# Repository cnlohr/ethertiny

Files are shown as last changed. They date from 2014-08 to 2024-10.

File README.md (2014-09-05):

WARNING

This is a really dangerous project.  Use at your own risk.

By directly ethernet without magnetics to an AVR, you may
cause serious damage, fire, or anything else crazy if there
is a DC offset.  It does not follow 802.3 standards for
10Base-T Ethernet

It has two projects in it:
 t85: uses differential signaling with fixed packets, similar to another
	person's project, igorplug, found here:
	http://www.cesko.host.sk/IgorPlugUSB/IgorPlug-USB%20%28AVR%29_eng.htm

 t85spi: uses the USI, and can send/receive arbitrary packets.

Schematics are in the "hardware/" folder.

See the youtube video for more info:

T85 Video:    http://youtu.be/mwcvElQS-hM

T85spi Video: http://youtu.be/m4f4OzEyueg

Paper on T85spi is found in the "paper/" folder.

Copyright (C) 2014 <>< Charles Lohr

Permission is hereby granted, free of charge, to any person obtaining a
copy of this software and associated documentation files (the "Software"),
to deal in the Software without restriction, including without limitation
the rights to use, copy, modify, merge, publish, distribute, sublicense,
and/or sell copies of the Software, and to permit persons to whom the
Software is furnished to do so, subject to the following conditions:

The above copyright notice and this permission notice shall be included
in all copies or substantial portions of the Software.

THE SOFTWARE IS PROVIDED "AS IS", WITHOUT WARRANTY OF ANY KIND, EXPRESS
OR IMPLIED, INCLUDING BUT NOT LIMITED TO THE WARRANTIES OF
MERCHANTABILITY, FITNESS FOR A PARTICULAR PURPOSE AND NONINFRINGEMENT.
IN NO EVENT SHALL THE AUTHORS OR COPYRIGHT HOLDERS BE LIABLE FOR ANY
CLAIM, DAMAGES OR OTHER LIABILITY, WHETHER IN AN ACTION OF CONTRACT,
TORT OR OTHERWISE, ARISING FROM, OUT OF OR IN CONNECTION WITH THE
SOFTWARE OR THE USE OR OTHER DEALINGS IN THE SOFTWARE.

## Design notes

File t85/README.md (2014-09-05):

This program just bit bangs data out a differential pair.
Whatever you put as your packet, it will parrot out at 
10 Mbit/sec.

The idea is you modify testpack.txt to be the following from:

:Function Name

[Ethernet bytes in hexadecmil, two letters each]

 ; Anything after a [space] and a semicolon is a comment.

Then, it will create "sendpack.S" with all of the assembly
to go run everything all at once.  In order to send a packet,
simply call the function to send a packet!

If you need to use the other ports for I/O, you'll need
to modify the code to set up the right bits on port B.

Right now, port PB3,PB4 are the TX+/TX- pins.
A switch can be connected between PB0 and PB1
and another switch may be connected btween PB2 and PB1.

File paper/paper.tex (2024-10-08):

%\documentclass{article}
\documentclass[13pt]{ltxdoc}
\usepackage{graphicx}
\usepackage[margin=1.25in]{geometry}
\usepackage[usenames,dvipsnames]{color}
\usepackage{hyperref}
\usepackage{listings}
\usepackage{float}
%\usepackage{draftwatermark}
%\SetWatermarkText{DRAFT}
%\SetWatermarkScale{8}
\restylefloat{figure}

\begin{document}

\title{Half-Duplex 10Base-T on an ATtiny85}
\author{Charles Lohr}
%\publicationyear{2014}
%\publicationissue{}
%\publicationmonth{September}
\maketitle

\begin{abstract}
The ATtiny85 Processor by Atmel is an 8-bit RISC microcontroller with 8kB of 
flash, 512 bytes of RAM, and a nominal operating frequency of 20 MHz.
10Base-T Ethernet is an interface standard supported by most modern networking
hardware and enables devices to talk to eachother on a network.  Ordinarily,
specialty hardware is needed to send and receive.  However, by abusing
the USI and PLL and overclocking the ATtiny85 processor, while violating the 802.3 standard, we can communicate to devices via 10Base-T on a network.
\end{abstract}

\begin{figure}[ht]
    \centering
    
    \caption{System Schematic}
	\label{fig:schematic}
\end{figure}

\section*{Warning}
This project does not follow standards, and violates recommended operating ranges on the AVR.  It is unlikely
to work with most AVRs or Ethernet-enabled devices, and is completely unacceptable for production designs.
Follow only at your own risk.
\pagebreak
\section{Introduction}

Although there have been those who have successfully sent packets from an AVR to
the Ethernet on an AVR\footnote{Igor \v{C}e\v{s}ko ``Implementation UDP into microcontroller Igor Atmel-UDP device: UDP/IP infrared remote control'' \url{http://www.cesko.host.sk/IgorPlugUDP/IgorPlug-UDP\%20\%28AVR\%29_eng.htm} (Retrieved Sept 2, 2014)}, their approaches have been limited
to fixed packets with at most one byte of payload changing.  This is not ideal
for a general Ethernet device.

The ATtiny85 processor has a core that operates at one clock cycle per instruction
for most instructions\footnote{Atmel ``8-bit AVR Instruction Set'' 0856D–AVR–08/02 (Retrieved Sept 2, 2014)}.  It has a USI (Universal Serial Interface)
that we can use as a high frequency shift register.  If clocked with Timer 0, 
we can achieve a sample rate of the system clock frequency.  This makes it possible
to send out Manchester-encoded Ethernet frames from RAM when operating at 20 MHz. 

When receiving packets, we need to sample at $\approx$31.5 MHz.  This can be achieved
by using the AVR's internal PLL.  Once the AVR is running above 30 MHz, the USI's 
buffer register is polled.  When an Ethernet frame begins, the AVR can dump the 
bitstream to RAM, and at a later time can decode the Ethernet frame in place.

Our physical interface to the Ethernet is intentionally poor and cheap, as can be seen in
Figure \ref{fig:schematic}.  While
it would be wise in more practical situations to use magnetics and proper termination
even a line driver would be great.  We opted to see what the bare minimum is.

\section{Background}

\subsection{Ethernet Topology}
Ethernet uses a point-to-point communication scheme over separate differential pairs of copper wires, one pair for TX one pair for RX. 
All communication to other devices on the network
is done through the use of switches and hubs.  Switches expect the TX and RX lines to
be opposite that of the client device.  We use the client-style +/- pairs.  If we wish
to connect directly to another client, i.e. a laptop, we would need a crossover or the
other computer would need to support MDIX.

The pairs, TX and RX are differential to aid in common-mode rejection.  Noise
will affect both pairs similarly, and the effective noise on the signal will be minimized.
Additionally, 802.3-2002 mandates all Ethernet devices isolated
the incoming signal to help with noise rejection and prevent ground loop issues, but
most prominently, safety benefits.  \footnote{802.3-2002 Section 14.3.1.1}

While detectable, it generally is not a big deal if the +/- on an individual pair
is swapped.  Our algorithm doesn't care which one is + or -.

Because we ground our signals instead of using magnetics, we will get neither of these
benefits.

\subsection{Manchester Encoding}
Ethernet data is encoded in Manchester encoding at 10 MBits/sec.  Manchester encoding
is a continuous stream that focuses on the changes in bits.

With Manchester decoding, focus is on the location of a rising or falling edge.  Falling 
edges on clock pulses indicate a 0, rising edges indicate a 1.  Manchester guarantees that there
should be approximately as many 1's on the wire as 0's, thus preventing DC offsets.  Figure \ref{manchester}
shows an example Manchester encoded stream.  

This data is transmitted on-wire MSB first.  At any one point in time, it is impossible to
determine if a bit is a 1 or a 0 unless the start-of-message bit is found, as there is no
clock source for Ethernet.  Therefore, it is impossible to know if the signal is falling or
rising on the clock edge.

\begin{figure}
    \centering
    
    \caption{Manchester Example}
    \label{manchester}
\end{figure}

One way to decode the Manchester if you know what the first bit is, is to look for any long pulses.
Each long pulse indicates a change in bits, and any pairs of short pulses indicate a repeat in bit. 
When the data transitions from a 0 to a 1 or a 1 to a 0, there is a long pulse. For
the section of the packet with many 0's, there are pairs of short pulses.  Making sure that all
short pulses are paired up helps us detect errors early. 

If there are many repeated output 1's or 0's in a row that can mark the end of an Ethernet packet.
While the Ethernet packet is transmitting, there should never be a period when the line is low
or high for longer than .2us.

In order to match up the first bit of the packet, we have to look for the start signature.
Figure \ref{manchesterb} shows what the beginning of the data in an Ethernet packet looks like.
Once we see the pair of 1's, we now know that the packet is starting and can begin 
decoding the packet.

\begin{figure}
    \centering
    
    \caption{Beginning of frame}
    \label{manchesterb}
\end{figure}

\subsection{IEEE 802.3 Ethernet frame}
The Ethernet frame consists of a preamble, i.e. repeating 0x55's for 7 bytes, with the last
byte being a 0xD5, i.e. the highest bit is flipped to break the chain of alternating low
and high.  This makes it possible for receivers to sync up to the packet at any time during the
preamble.  This can be seen in Figure \ref{manchesterb}.  Practically speaking that gives us $\approx$5uS to begin recording an Ethernet 
before we'll miss the start token and be unable to recover the packet.

Figure \ref{etherfarme} shows us that from there, we have the destination MAC, source MAC, and the rest of our IP packet.
When we're done with the IP Packet, we can have padding so that the frame adds up to 64 bytes, and then at the end, we have an Ethernet CRC.
We had to use a table-less CRC because of the excessive RAM/Flash usage of tabled ones.

\begin{figure}
    \centering
    
    \caption{Ethernet Packet Example}
    \label{etherfarme}
\end{figure}

\subsection{Link Detection}
Ethernet Links are detected using different autonegotiation schemes depending on speed.  Conveniently,
10Base-T, Half-Duplex is trivial to indicate.  It does not need any codes and simply needs to emit
a new NLP pulse every 16ms that's 100-200ns wide.  This pulse is only in one direction and is not a full
up-and-down.

\section{Hardware}
Figure \ref{fig:schematic} shows the specific schematic we used when developing the software stack.
It is particularly terrible.  It terminates poorly, doesn't have any isolation, doesn't drive very strong (violating the
voltage template) \footnote{IEEE 802.3-2002 Figure 14-9}
and doesn't cleanly receive data.  This is the most minimal set up we were able to use to send and receive packets.

While it worked with short cables (\textless 10 meters) with all hardware we connected it.  When tested \textgreater 10 meters,
to a switch it did not link.

\begin{itemize}
\item C1, C2 are bypass capacitors that maintain power to the chip during brief points where it needs extra power, i.e. transitioning states on the TX pin.
\item P1 is any ethernet connector, it may be female or male.
\item C3 is the TX capacitor.  It develops a 2.5v bias, so the output swing (if no load were applied) would be $\pm$2.5v.
\item C4 is the RX capacitor.  It develops a biased voltage across, so the AVR does not interface with negative voltages.
\item R1, R2 produce a bias in order to raise or lower the DC offset of the incoming signal so that the AVR receives approximately as many 1's as 0's.  It also helps prevent state transitions from being missed entirely.  2k was selected because it happens to have lined up with what I had and worked surprisingly well.
\item R3, R4 are termination resistors, to terminate the signal from the network cable.
\item U1 is the ATtiny85 Processor.
\item J1 is the programming header, compliant with the 6-pin AVR ISP header.
\item WS2812 is any series of WS2812 LEDs.
\item SW1 is a switch.  Because PB4 has an internal pull-up resistor.  This switch will ground that pin.
\end{itemize}

Hardware warnings include:
\begin{itemize}
\item The AVR is driving the output directly, and will often be unable to push the output hard enough to reach the needed voltages to match the spec, also it has a noisy output.
\item There is no isolation.  There should be magnetics to help to:
\begin{itemize}
\item Reject common-mode noise, cleaning up the signal.
\item Add safety to prevent DC transients.
\end{itemize}
\item There is no differential receiver. We are relying on the AVR's Schmitt trigger. \footnote{AVR ATtiny85 Datasheet (2586K-AVR-01/08), Figure 10-2}
\end{itemize}

\section{Software Implementation}
IEEE 802.3 specifies a few different speeds for Ethernet.  One of which that is still
widely supported is 10Base-T, which runs at 10 mbits/sec on-wire transfer - and Ethernet
devices today are still reverse compatible with it.
\textsuperscript{IEEE 802.3 Section 28.1.4}.  We will
mimic a 10Base-T device.  For this we will focus on these aspects:

\begin{itemize}
\item Clocking
\item Use of the USI (Universal Serial Interface)
\item Normal Link Pulses (NLP)
\item Transmitting Manchester encoded packets
\item Receiving Manchester encoded packets
\item Overall process.
\end{itemize}

All source code is available on github in the "ethertiny" project.  At the time
of initially writing this paper, all code for this paper was in the "t85spi" folder.

\subsection{Clock}
We opted to
use the USI on the ATtiny85, clocked at the system clock.  This enables us to
write one byte at a time that will be shifted out of the USI over the next eight
clock cycles.  This gives us enough time to Manchester encode bytes of Ethernet
traffic in RAM on-the-fly.  This is good because it means we do not need to pre-
process the packet and we do not need to use extra RAM to store it.

In order to obtain 20 MHz, we arbitrarily picked an OSCCAL value of 0xbb on our
hardware.  Although this should change from chip to chip, we've found that in most
cases, surprisingly, this value seems to hold.  Additionally, we have to configure
the clock fuses to CKSEL=1.  Our fuses for this are found in Listing \ref{lst:avrdude_fuses}.
Default EFUSEs and HFUSEs are acceptable.  We also enable PLLE and PCKE for any additional
hardware as seen in Listing \ref{lst:clkcmd}.

\begin{figure}
\begin{lstlisting}[caption=AVRDude Fuse Command Line\label{lst:avrdude_fuses},, frame=single]
avrdude -c usbtiny -p t85 -U lfuse:w:0x41:m
\end{lstlisting}
\end{figure}

\begin{figure}
\begin{lstlisting}[caption=Clock Setup\label{lst:clkcmd},language=C, frame=single]
PLLCSR = _BV(PLLE) | _BV( PCKE );
OSCCAL = OSC20;
\end{lstlisting}
\end{figure}

To move to $\approx$31.5 MHz for receiving, we simply set OSCCAL to 0xff.  Once done, we move it back to 0xbb for all other operations.

\subsection{USI}
The USI on the ATtiny must be clocked at the system clock in order to input and output the data fast enough.
To do this, we configure Timer 0 to clock at the system clock rate in CTC mode, with a "top" time of 0.
Provided we operate on it every eight clock cycles, we can create or read
a continuous stream of 1's and 0's at the clock rate.

Listing \ref{lst:usisetup} shows the code to activate Timer 0 and configure the USI to use it. 
When reading from the USI, it is important to use the USIDR registers whenever reading or writing to it.

We have to keep the USI disabled when not in use.  If we leave it enabled, data coming in will be shifted through.  
That means that whenever the USI is enabled, we must be constantly filling the incoming buffer or reading the buffer.
We do not want the incoming data from the network to be shifted back out.  It is convenient to leave the USICR setup and then
set the flag to enable it once we're ready to load in new data and go.

\begin{figure}
\begin{lstlisting}[caption=USI Setup\label{lst:usisetup},language=C, frame=single]

	//Setup timer 0 to speed along.
	//It will become useless for any other uses.
	TCCR0A = _BV(WGM01); //CTC mode.
	TCCR0B = _BV(CS00);  //Use system clock with no divisor.
	OCR0A = 0;

	USICR = _BV(USIWM0) | _BV(USICS0) | _BV(USITC);

	//setup port B
	PORTB &= ~_BV(0); 
	DDRB &= ~_BV(0);
	PORTB &= ~_BV(1);
	USICR &= ~_BV(USIWM0);  //Disable USICR

#ifdef SMARTDDR
	DDRB &= _BV(1);
#else
	DDRB |= _BV(1);
#endif

	//Optional, changes bias.
	//2k -> GND/2k ->5V seems best with this on
	//PORTB |= _BV(0);
	//Doesn't change much with it off. 2k/2k it is.
	PORTB &= ~_BV(0);

\end{lstlisting}
\end{figure}

\subsection{NLPs}
10Base-T Ethernet uses link pulses, or a single up-going pulse that lasts 10-20us
every 16ms $\pm$ 8ms \textsuperscript{IEEE802.3 Section 14.2.1.1}.  This is used to tell
the connected Ethernet device that this device is here, that it's alive, and that it's a
10Base-T, Half-duplex device.  Instead of using the USI on the AVR to create this
signal, we opt to manually turn the pin on and off at the correct times in
Listing \ref{lst:nlp_code}.  Provided the USI is turned off, DDRB is configured as
an output (or SMARTDDR is enabled), and we're operating at 30 MHz.  This will produce an $\approx$80ns to $\approx$120ns pulse.

\begin{figure}
\begin{lstlisting}[caption=NLP Code\label{lst:nlp_code}, frame=single]
	sbi PORTB, 1
#ifdef SMARTDDR
	sbi DDRB, 1
#endif
	nop  //~80ns from on to off
#ifdef LONGNLP 
	nop  //+40ns
#endif
#ifdef SMARTDDR
	cbi DDRB, 1
#endif
	cbi PORTB, 1
\end{lstlisting}
\end{figure}

It would be useful to note here what ``SMARTDDR'' is.  Because we have a capacitor to decouple the DC from the TX line,
it is many times advantageous to leave the pin disconnected except when it is in use.  This will help keep the bias
across the capacitor to 2.5V, so when the pin is turned high or low, it can create the $\pm$2.5v swing 10Base-T uses.

\subsection{TX Manchester-encoded packets}
When operating at 20 MHz, it would be possible to manually bit-bang out a message
via two GPIOs.  If we do that, we also get the added bonus of differential
signaling.  However, if we do this, then there is very little room to modify
the packet.  In fact, we would only be able to modify at most one byte and a
few bits.

\begin{figure}
\begin{lstlisting}[caption=Manchester Lookup Table\label{lst:mantable},language=C, frame=single]
char ManchesterTable[16] __attribute__
	((aligned (16))) = {
	0b10101010, 0b01101010,
	0b10011010, 0b01011010,
	0b10100110, 0b01100110,
	0b10010110, 0b01010110,
	0b10101001, 0b01101001,
	0b10011001, 0b01011001,
	0b10100101, 0b01100101,
	0b10010101, 0b01010101,
};
\end{lstlisting}
\end{figure}

We can store a pre-computed Manchester, Listing \ref{lst:mantable} table for each possible nibble of output
and look up into that table while we're shifting the data out.  In that table, the data in address
0 represents the data that would need to be shifted out to represent a binary 0000, the value in address
address 13 ``d'' (1011 binary), is 01100101, pattern we saw in Figure \ref{manchesterb}.  The reason for the alignment
is because the bottom nibble of its address must be 0x0, so we can use bitwise operations to look up
into the table.

The function that handles sending packets is SendTestASM, and it is written in assembler for the AVR as
to tightly control the timing of writing to the USIDR register.  Figure \ref{sendexplain} shows the progression
of a transmit operation. We first
read the byte we want to send out of RAM, look at its bottom nibble, look that up in the Manchester
table, send the bottom nibble's  Manchester, read the high nibble, look it up in the Manchester table, and
send that.  Then, we look at the next byte and do the same, all in groups of 4 bytes.

\begin{figure}
    \centering
    
    \caption{High-level SendTestASM}
    \label{sendexplain}
\end{figure}

Unfortunately, in order to actually accomplish this, we have to heavily interleave the code.  The 
reason we must interleave the code is some operations such as checking to see if we are done with
sending all of the bytes take three operations, and there is only one free operation every time
we send another byte.  By sending groups of four bytes, that extra free cycle we gain per-byte can build up so we can
do our three-cycle compare and jump at the end.  

\subsection{RX Manchester-encoded packets}
\label{rxmch}
Doing the Manchester decoding is the difficult part.  Without using external hardware to lock onto
the loop, or to detect the phase, it means we have to do that entirely with the AVR.  Because it is
also difficult to tweak the AVR's clock to get in phase with the Ethernet signal, we opted to 
stream the bits in software.

Manchester encoding can be decoded entirely in software with a sample rate that exceeds three
times the symbol rate.  That would means our AVR would have to run above 30 MHz, which
conveniently is possible.

By sampling at three times the rate, we can identify ``Long'' and ``Short'' transitions.  Additionally,
the fact that a signal is a ``1'' or a ``0'', incoming becomes irrelevant, and we can focus only on
the transitions.  In order to read in the data, we operate in much the same way we TX'ed the packet.  However
we need to wait for a reading from USIDR that is not 0x00 or 0xff, i.e. it contains both 1 and 0 bits. That
would mean we likely have a packet.

Once we see that change, provided we're operating at $\approx$31.5 MHz, we can begin to capture the packet
by continuously reading USIDR every eight cycles.  After every two packets, we can check to see if
it is all 1's or all 0's.  If it is, we can stop, if not, we continue to capture to RAM.

To understand how we can go from a Manchester bitstream to a series of 1's and 0's, we first
have to understand how we can determine the difference between short and long transitions.  Figure
\ref{demanchester} shows this conversion in the creation of the ``counts'' row from the ``values'' row.
Once we have them, we can pair the shorts together and identify whether bits are flipping or not.

Considering that we can look for the start of packet flag, the 0xD5 from the beginning, we can maintain
whether the current bit is a 0 or a 1 throughout the life of the packet.

\begin{figure}
    \centering
    
    \caption{Demanchestration (33 MHz clock)}
    \label{demanchester}
\end{figure}

A copy of the Demanchestrate function can be found in the code tree in \texttt{hlprocess.c}.

It is important to note that Demanchestrating the packet can be done in-place.  It is
safe to overwrite the raw data with the packet as it is decoded because the packet is always shorter
than the raw data coming in.

Once a packet is decoded, provided there are no bit errors, i.e. unmatched shorts, or missed
shorts, we can begin the CRC \footnote{CRC Code from: http://www.hackersdelight.org/hdcodetxt/crc.c.txt}.  We can use the same CRC that we use for sending in order to verify that the packet
was received successfully.

From there, we can pass it to the IP stack, where it will deal with the packet.  An IP 
stack is outside the scope of this document.

\subsection{Overall Process}
We configure the pin change interrupt on PB0 so that if data ever comes in, we can start watching that line to see if it's a spurious data, a NLP, FLP or the beginnings of a packet. 
If it's a packet, we start recording the pin as described in Section \ref{rxmch}

We configure timer 1 to operate on a 4ms period and set it up to fire an interrupt. After 4 ticks,
we then send a NLP.  This timer can also be used to clock other higher level aspects
of the chip and drive PWM if needed.  The NLPs can be sent by an arbitrary means, so long as they are
sent out approximately every 16ms.

Our main loop waits to see when the NLP timer advances.  We can schedule things to happen whenever in this loop. 
Every 4 NLPs, we fire a broadcast packet.  

Whenever user code locks interrupts, the system cannot receive.  If we continue locked until there insufficient
preamble for the demanchestrate function to operate on, we will drop a packet.  User code can use interrupts freely as well
(given the same caveat).

User code can also send packets either in response to existing packets in the HandleUDP function or anywhere in code.

As a warning, interrupts are disabled while the system is receiving a packet.

\section{Conclusion}
We have been able to implement a UDP/IP stack with ARP, UDP, and ICMP on an attiny85.  We have tested it
with short wire runs to a few different types of switches and computers and found that we could communicate.
We can send and receive packets up to a $\approx$90-bytes on-wire or 48-bytes of UDP payload.
We have had moderate packet loss, on the order of 5-20 \% of the packets.  This is important
when considering applications for this technology, as all protocols the user would have to use must be
robust, able to handle lost packets gracefully, and must not be CPU intensive.

Additionally, because the stack takes a considerable amount of RAM, very little RAM is left over for user
applications unless the user decides to tune back the stack's buffer - which would further limit the 
maximum packet size.

When operating at full speed, our stack uses $\approx$25 mA at 4.5v - less than 1/8 of a watt.

Though impractical for most applications, this stack may prove useful in niche applications where 
cost, power size or other factors outweigh robustness, transfer speeds, or reliability.

\section{Future Work}
We could do a number of things from here that would be useful and interesting.  A few are listed below:

\begin{itemize}
\item Use T0 input from PLL PWM on the AVR to increase sampling rate to 35 MHz, to improve input performance.
\item Use a differential driver/receiver to drive the actual signal.
\item Add magnetics and examine performance.
\item Use the internal pull-up to tune the bias, detect if this pull-up helps somehow.
\item Optimize the Demanchestration function in assembly.
\item Automatically calibrate the proper OSCCAL for sending based on incoming packets.
\item Improve error correction based on matching pairs and long/short segments. (Improvements to the Demanchestrate function)
\end{itemize}

\end{document}

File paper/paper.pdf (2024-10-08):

# Half-Duplex 10Base-T on an ATtiny85

Charles Lohr

October 8, 2024

Abstract

The ATtiny85 Processor by Atmel is an 8-bit RISC microcontroller with 8kB of flash, 512 bytes of RAM, and a nominal operating frequency of 20 MHz. 10Base-T Ethernet is an interface standard supported by most modern networking hardware and enables devices to talk to eachother on a network. Ordinarily, specialty hardware is needed to send and receive. However, by abusing the USI and PLL and overclocking the ATtiny85 processor, while violating the 802.3 standard, we can communicate to devices via 10Base-T on a network.

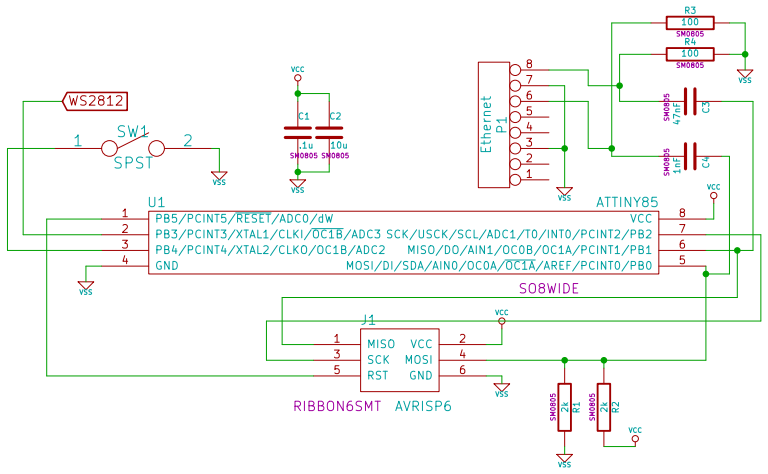
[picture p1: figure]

Figure 1: System Schematic

## Warning

This project does not follow standards, and violates recommended operating ranges on the AVR. It is unlikely to work with most AVRs or Ethernet-enabled devices, and is completely unacceptable for production designs. Follow only at your own risk.

## 1 Introduction

Although there have been those who have successfully sent packets from an AVR to the Ethernet on an AVR¹
, their approaches have been limited to fixed packets with at most one byte of payload changing. This is not ideal for a general Ethernet device.
The ATtiny85 processor has a core that operates at one clock cycle per instruction for most instructions²
. It has a USI (Universal Serial Interface) that we can use as a high frequency shift register. If clocked with Timer 0, we can achieve a sample rate of the system clock frequency. This makes it possible to send out Manchester-encoded Ethernet frames from RAM when operating at 20 MHz.
When receiving packets, we need to sample at ≈31.5 MHz. This can be achieved by using the AVR’s internal PLL. Once the AVR is running above 30 MHz, the USI’s buffer register is polled. When an Ethernet frame begins, the AVR can dump the bitstream to RAM, and at a later time can decode the Ethernet frame in place.
Our physical interface to the Ethernet is intentionally poor and cheap, as can be seen in Figure 1. While it would be wise in more practical situations to use magnetics and proper termination even a line driver would be great. We opted to see what the bare minimum is.

## 2 Background

### 2.1 Ethernet Topology

Ethernet uses a point-to-point communication scheme over separate differential pairs of copper wires, one pair for TX one pair for RX. All communication to other devices on the network is done through the use of switches and hubs. Switches expect the TX and RX lines to be opposite that of the client device. We use the client-style +/- pairs. If we wish to connect directly to another client, i.e. a laptop, we would need a crossover or the other computer would need to support MDIX.
The pairs, TX and RX are differential to aid in common-mode rejection. Noise will affect both pairs similarly, and the effective noise on the signal will be minimized. Additionally, 802.3-2002 mandates all Ethernet devices isolated the incoming signal to help with noise rejection and prevent ground loop issues, but most prominently, safety benefits. 3
While detectable, it generally is not a big deal if the +/- on an individual pair is swapped. Our algorithm doesn’t care which one is + or -.
Because we ground our signals instead of using magnetics, we will get neither of these benefits.

### 2.2 Manchester Encoding

Ethernet data is encoded in Manchester encoding at 10 MBits/sec. Manchester encoding is a continuous stream that focuses on the changes in bits.
With Manchester decoding, focus is on the location of a rising or falling edge. Falling edges on clock pulses indicate a 0, rising edges indicate a 1. Manchester guarantees that there should be approximately as many 1’s on the wire as 0’s, thus preventing DC offsets. Figure 2 shows an example Manchester encoded stream.
This data is transmitted on-wire MSB first. At any one point in time, it is impossible to determine if a bit is a 1 or a 0 unless the start-of-message bit is found, as there is no clock source for Ethernet. Therefore, it is impossible to know if the signal is falling or rising on the clock edge.
One way to decode the Manchester if you know what the first bit is, is to look for any long pulses. Each long pulse indicates a change in bits, and any pairs of short pulses indicate a repeat in bit. When the data transitions from a 0 to a 1 or a 1 to a 0, there is a long pulse. For the

1

Igor Ceˇsko “Implementation UDP into microcontroller Igor Atmel-UDP device: UDP/IP infrared remote ˇ control” http://www.cesko.host.sk/IgorPlugUDP/IgorPlug-UDP%20%28AVR%29_eng.htm (Retrieved Sept 2, 2014) 2Atmel “8-bit AVR Instruction Set” 0856D–AVR–08/02 (Retrieved Sept 2, 2014)
3802.3-2002 Section 14.3.1.1

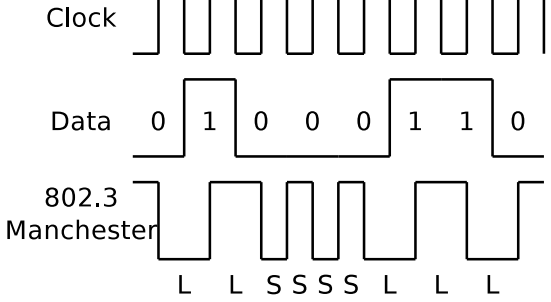
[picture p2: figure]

Figure 2: Manchester Example

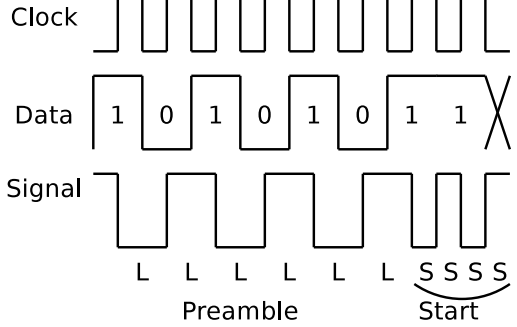
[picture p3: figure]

Figure 3: Beginning of frame

section of the packet with many 0’s, there are pairs of short pulses. Making sure that all short pulses are paired up helps us detect errors early.
If there are many repeated output 1’s or 0’s in a row that can mark the end of an Ethernet packet. While the Ethernet packet is transmitting, there should never be a period when the line is low or high for longer than .2us.
In order to match up the first bit of the packet, we have to look for the start signature. Figure 3 shows what the beginning of the data in an Ethernet packet looks like. Once we see the pair of 1’s, we now know that the packet is starting and can begin decoding the packet.

### 2.3 IEEE 802.3 Ethernet frame

The Ethernet frame consists of a preamble, i.e. repeating 0x55’s for 7 bytes, with the last byte being a 0xD5, i.e. the highest bit is flipped to break the chain of alternating low and high. This makes it possible for receivers to sync up to the packet at any time during the preamble. This can be seen in Figure 3. Practically speaking that gives us ≈5uS to begin recording an Ethernet before we’ll miss the start token and be unable to recover the packet.
Figure 4 shows us that from there, we have the destination MAC, source MAC, and the rest of our IP packet. When we’re done with the IP Packet, we can have padding so that the frame adds up to 64 bytes, and then at the end, we have an Ethernet CRC. We had to use a table-less CRC because of the excessive RAM/Flash usage of tabled ones.

### 2.4 Link Detection

Ethernet Links are detected using different autonegotiation schemes depending on speed. Conveniently, 10Base-T, Half-Duplex is trivial to indicate. It does not need any codes and simply needs to emit a new NLP pulse every 16ms that’s 100-200ns wide. This pulse is only in one direction and is not a full up-and-down.

Figure 4: Ethernet Packet Example

## 3 Hardware

Figure 1 shows the specific schematic we used when developing the software stack. It is par-ticularly terrible. It terminates poorly, doesn’t have any isolation, doesn’t drive very strong (violating the voltage template) 4 and doesn’t cleanly receive data. This is the most minimal set up we were able to use to send and receive packets.
While it worked with short cables (<10 meters) with all hardware we connected it. When tested >10 meters, to a switch it did not link.
| C1, C2 are bypass capacitors that maintain power to the chip during brief points where it needs extra power, i.e. transitioning states on the TX pin.
| P1 is any ethernet connector, it may be female or male.
| C3 is the TX capacitor. It develops a 2.5v bias, so the output swing (if no load were applied) would be ±2.5v.
| C4 is the RX capacitor. It develops a biased voltage across, so the AVR does not interface with negative voltages.
| R1, R2 produce a bias in order to raise or lower the DC offset of the incoming signal so that the AVR receives approximately as many 1’s as 0’s. It also helps prevent state transitions from being missed entirely. 2k was selected because it happens to have lined up with what I had and worked surprisingly well.
| R3, R4 are termination resistors, to terminate the signal from the network cable.
| U1 is the ATtiny85 Processor.
| J1 is the programming header, compliant with the 6-pin AVR ISP header.
| WS2812 is any series of WS2812 LEDs.
| SW1 is a switch. Because PB4 has an internal pull-up resistor. This switch will ground that pin.

Hardware warnings include:

| The AVR is driving the output directly, and will often be unable to push the output hard enough to reach the needed voltages to match the spec, also it has a noisy output.
| There is no isolation. There should be magnetics to help to:
| – Reject common-mode noise, cleaning up the signal. – Add safety to prevent DC transients.
| There is no differential receiver. We are relying on the AVR’s Schmitt trigger. 5

4
IEEE 802.3-2002 Figure 14-9
5AVR ATtiny85 Datasheet (2586K-AVR-01/08), Figure 10-2

Listing 1: AVRDude Fuse Command Line

avrdude =c u s b ti n y =p t 8 5 =U l f u s e :w: 0 x41 :m

Listing 2: Clock Setup
PLLCSR = BV (PLLE) | BV ( PCKE ) ;
OSCCAL = OSC20 ;

## 4 Software Implementation

IEEE 802.3 specifies a few different speeds for Ethernet. One of which that is still widely supported is 10Base-T, which runs at 10 mbits/sec on-wire transfer - and Ethernet devices today are still reverse compatible with it. IEEE 802.3 Section 28.1.4. We will mimic a 10Base-T device. For this we will focus on these aspects:

| Clocking
| Use of the USI (Universal Serial Interface)
| Normal Link Pulses (NLP)
| Transmitting Manchester encoded packets
| Receiving Manchester encoded packets
| Overall process.

All source code is available on github in the ”ethertiny” project. At the time of initially writing this paper, all code for this paper was in the ”t85spi” folder.

### 4.1 Clock

We opted to use the USI on the ATtiny85, clocked at the system clock. This enables us to write one byte at a time that will be shifted out of the USI over the next eight clock cycles. This gives us enough time to Manchester encode bytes of Ethernet traffic in RAM on-the-fly. This is good because it means we do not need to pre- process the packet and we do not need to use extra RAM to store it.
In order to obtain 20 MHz, we arbitrarily picked an OSCCAL value of 0xbb on our hardware. Although this should change from chip to chip, we’ve found that in most cases, surprisingly, this value seems to hold. Additionally, we have to configure the clock fuses to CKSEL=1. Our fuses for this are found in Listing 1. Default EFUSEs and HFUSEs are acceptable. We also enable PLLE and PCKE for any additional hardware as seen in Listing 2.
To move to ≈31.5 MHz for receiving, we simply set OSCCAL to 0xff. Once done, we move it back to 0xbb for all other operations.

### 4.2 USI

The USI on the ATtiny must be clocked at the system clock in order to input and output the data fast enough. To do this, we configure Timer 0 to clock at the system clock rate in CTC mode, with a ”top” time of 0. Provided we operate on it every eight clock cycles, we can create or read a continuous stream of 1’s and 0’s at the clock rate.
Listing 3 shows the code to activate Timer 0 and configure the USI to use it. When reading from the USI, it is important to use the USIDR registers whenever reading or writing to it. We have to keep the USI disabled when not in use. If we leave it enabled, data coming in will be shifted through. That means that whenever the USI is enabled, we must be constantly

Listing 3: USI Setup

// Se tup t ime r 0 t o s pee d al o n g .
// I t w i l l become u s e l e s s f o r any o t h e r u s e s .
TCCR0A = BV (WGM01) ; //CTC mode .
TCCR0B = BV ( CS00 ) ; //Use sys tem c l o c k w i t h no d i v i s o r . OCR0A = 0 ;
USICR = BV (USIWM0) | BV ( USICS0 ) | BV (USITC ) ;

// s e t u p p o r t B
PORTB &= ˜ BV ( 0 ) ;
DDRB &= ˜ BV ( 0 ) ;
PORTB &= ˜ BV ( 1 ) ;
USICR &= ˜ BV (USIWM0 ) ; // D i s a b l e USICR

#i f d e f SMARTDDR

DDRB &= BV ( 1 ) ;
#e l s e

DDRB |= BV ( 1 ) ;
#end i f

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

filling the incoming buffer or reading the buffer. We do not want the incoming data from the network to be shifted back out. It is convenient to leave the USICR setup and then set the flag to enable it once we’re ready to load in new data and go.

### 4.3 NLPs

10Base-T Ethernet uses link pulses, or a single up-going pulse that lasts 10-20us every 16ms ± 8ms IEEE802.3 Section 14.2.1.1. This is used to tell the connected Ethernet device that this device is here, that it’s alive, and that it’s a 10Base-T, Half-duplex device. Instead of using the USI on the AVR to create this signal, we opt to manually turn the pin on and off at the correct times in Listing 4. Provided the USI is turned off, DDRB is configured as an output (or SMARTDDR is enabled), and we’re operating at 30 MHz. This will produce an ≈80ns to ≈120ns pulse.
It would be useful to note here what “SMARTDDR” is. Because we have a capacitor to decouple the DC from the TX line, it is many times advantageous to leave the pin disconnected except when it is in use. This will help keep the bias across the capacitor to 2.5V, so when the pin is turned high or low, it can create the ±2.5v swing 10Base-T uses.

### 4.4 TX Manchester-encoded packets

When operating at 20 MHz, it would be possible to manually bit-bang out a message via two GPIOs. If we do that, we also get the added bonus of differential signaling. However, if we do this, then there is very little room to modify the packet. In fact, we would only be able to modify at most one byte and a few bits.
We can store a pre-computed Manchester, Listing 5 table for each possible nibble of output and look up into that table while we’re shifting the data out. In that table, the data in address

Listing 4: NLP Code
s b i PORTB, 1
#i f d e f SMARTDDR

s b i DDRB, 1
#e n d i f

nop //˜80 ns from on t o o f f #i f d e f LONGNLP
nop //+40 ns
#e n d i f

#i f d e f SMARTDDR

c bi DDRB, 1
#e n d i f

c bi PORTB, 1

Listing 5: Manchester Lookup Table char ManchesterTable [ 1 6 ] a t t r i b u t e ( ( ali g n e d ( 1 6 ) ) ) = {
0 b10101010 , 0 b01101010 , 0 b10011010 , 0 b01011010 , 0 b10100110 , 0 b01100110 , 0 b10010110 , 0 b01010110 , 0 b10101001 , 0 b01101001 , 0 b10011001 , 0 b01011001 , 0 b10100101 , 0 b01100101 , 0 b10010101 , 0 b01010101 , } ;

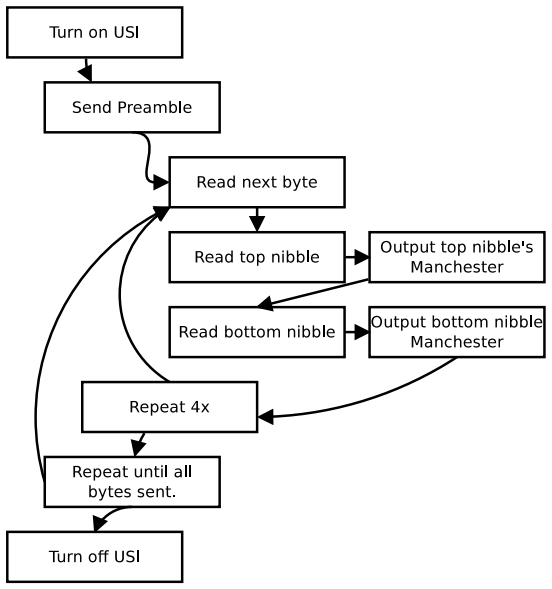
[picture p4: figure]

Figure 5: High-level SendTestASM

0 represents the data that would need to be shifted out to represent a binary 0000, the value in address address 13 “d” (1011 binary), is 01100101, pattern we saw in Figure 3. The reason for the alignment is because the bottom nibble of its address must be 0x0, so we can use bitwise operations to look up into the table.
The function that handles sending packets is SendTestASM, and it is written in assembler for the AVR as to tightly control the timing of writing to the USIDR register. Figure 5 shows the progression of a transmit operation. We first read the byte we want to send out of RAM, look at its bottom nibble, look that up in the Manchester table, send the bottom nibble’s Manchester, read the high nibble, look it up in the Manchester table, and send that. Then, we look at the next byte and do the same, all in groups of 4 bytes.
Unfortunately, in order to actually accomplish this, we have to heavily interleave the code. The reason we must interleave the code is some operations such as checking to see if we are done with sending all of the bytes take three operations, and there is only one free operation every time we send another byte. By sending groups of four bytes, that extra free cycle we gain per-byte can build up so we can do our three-cycle compare and jump at the end.

### 4.5 RX Manchester-encoded packets

Doing the Manchester decoding is the difficult part. Without using external hardware to lock onto the loop, or to detect the phase, it means we have to do that entirely with the AVR. Because it is also difficult to tweak the AVR’s clock to get in phase with the Ethernet signal, we opted to stream the bits in software.
Manchester encoding can be decoded entirely in software with a sample rate that exceeds three times the symbol rate. That would means our AVR would have to run above 30 MHz, which conveniently is possible.
By sampling at three times the rate, we can identify “Long” and “Short” transitions. Additionally, the fact that a signal is a “1” or a “0”, incoming becomes irrelevant, and we can focus only on the transitions. In order to read in the data, we operate in much the same way we TX’ed the packet. However we need to wait for a reading from USIDR that is not 0x00 or 0xff, i.e. it contains both 1 and 0 bits. That would mean we likely have a packet.
Once we see that change, provided we’re operating at ≈31.5 MHz, we can begin to capture the packet by continuously reading USIDR every eight cycles. After every two packets, we can check to see if it is all 1’s or all 0’s. If it is, we can stop, if not, we continue to capture to RAM.

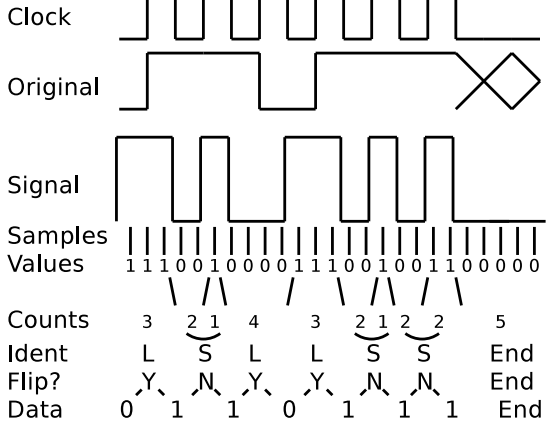
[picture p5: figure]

Figure 6: Demanchestration (33 MHz clock)

To understand how we can go from a Manchester bitstream to a series of 1’s and 0’s, we first have to understand how we can determine the difference between short and long transitions. Figure 6 shows this conversion in the creation of the “counts” row from the “values” row. Once we have them, we can pair the shorts together and identify whether bits are flipping or not. Considering that we can look for the start of packet flag, the 0xD5 from the beginning, we can maintain whether the current bit is a 0 or a 1 throughout the life of the packet.
A copy of the Demanchestrate function can be found in the code tree in hlprocess.c.
It is important to note that Demanchestrating the packet can be done in-place. It is safe to overwrite the raw data with the packet as it is decoded because the packet is always shorter than the raw data coming in.
Once a packet is decoded, provided there are no bit errors, i.e. unmatched shorts, or missed shorts, we can begin the CRC 6
. We can use the same CRC that we use for sending in order to verify that the packet was received successfully.
From there, we can pass it to the IP stack, where it will deal with the packet. An IP stack is outside the scope of this document.

### 4.6 Overall Process

We configure the pin change interrupt on PB0 so that if data ever comes in, we can start watching that line to see if it’s a spurious data, a NLP, FLP or the beginnings of a packet. If it’s a packet, we start recording the pin as described in Section 4.5
We configure timer 1 to operate on a 4ms period and set it up to fire an interrupt. After 4 ticks, we then send a NLP. This timer can also be used to clock other higher level aspects of the chip and drive PWM if needed. The NLPs can be sent by an arbitrary means, so long as they are sent out approximately every 16ms.
Our main loop waits to see when the NLP timer advances. We can schedule things to happen whenever in this loop. Every 4 NLPs, we fire a broadcast packet.
Whenever user code locks interrupts, the system cannot receive. If we continue locked until there insufficient preamble for the demanchestrate function to operate on, we will drop a packet. User code can use interrupts freely as well (given the same caveat).
User code can also send packets either in response to existing packets in the HandleUDP function or anywhere in code.
As a warning, interrupts are disabled while the system is receiving a packet.

6CRC Code from: http://www.hackersdelight.org/hdcodetxt/crc.c.txt

## 5 Conclusion

We have been able to implement a UDP/IP stack with ARP, UDP, and ICMP on an attiny85. We have tested it with short wire runs to a few different types of switches and computers and found that we could communicate. We can send and receive packets up to a ≈90-bytes on-wire or 48-bytes of UDP payload. We have had moderate packet loss, on the order of 5-20 % of the packets. This is important when considering applications for this technology, as all protocols the user would have to use must be robust, able to handle lost packets gracefully, and must not be CPU intensive.
Additionally, because the stack takes a considerable amount of RAM, very little RAM is left over for user applications unless the user decides to tune back the stack’s buffer - which would further limit the maximum packet size.
When operating at full speed, our stack uses ≈25 mA at 4.5v - less than 1/8 of a watt. Though impractical for most applications, this stack may prove useful in niche applications where cost, power size or other factors outweigh robustness, transfer speeds, or reliability.

## 6 Future Work

We could do a number of things from here that would be useful and interesting. A few are listed below:

| Use T0 input from PLL PWM on the AVR to increase sampling rate to 35 MHz, to improve input performance.
| Use a differential driver/receiver to drive the actual signal.
| Add magnetics and examine performance.
| Use the internal pull-up to tune the bias, detect if this pull-up helps somehow.
| Optimize the Demanchestration function in assembly.
| Automatically calibrate the proper OSCCAL for sending based on incoming packets.
| Improve error correction based on matching pairs and long/short segments. (Improvements to the Demanchestrate function)

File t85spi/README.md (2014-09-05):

This is a work-in-progress, but I'm trying to see if I can send + receive packets
on an ATTiny.  I don't know if I'm gonna work on it anymore.

This one is a little different than the last one.  It handles sending
arbitrary packets.

To understand what this does, you should probably read the paper in the 
"paper" root folder.

All schematics are available in the "hardware" root folder.

Copyright (C) 2014 <>< Charles Lohr

Permission is hereby granted, free of charge, to any person obtaining a
copy of this software and associated documentation files (the "Software"),
to deal in the Software without restriction, including without limitation
the rights to use, copy, modify, merge, publish, distribute, sublicense,
and/or sell copies of the Software, and to permit persons to whom the
Software is furnished to do so, subject to the following conditions:

The above copyright notice and this permission notice shall be included
in all copies or substantial portions of the Software.

THE SOFTWARE IS PROVIDED "AS IS", WITHOUT WARRANTY OF ANY KIND, EXPRESS
OR IMPLIED, INCLUDING BUT NOT LIMITED TO THE WARRANTIES OF
MERCHANTABILITY, FITNESS FOR A PARTICULAR PURPOSE AND NONINFRINGEMENT.
IN NO EVENT SHALL THE AUTHORS OR COPYRIGHT HOLDERS BE LIABLE FOR ANY
CLAIM, DAMAGES OR OTHER LIABILITY, WHETHER IN AN ACTION OF CONTRACT,
TORT OR OTHERWISE, ARISING FROM, OUT OF OR IN CONNECTION WITH THE
SOFTWARE OR THE USE OR OTHER DEALINGS IN THE SOFTWARE.

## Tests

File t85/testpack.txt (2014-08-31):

; Warning: you must have whitespace before the ;
; Don't worry, preamble and ethernet CRC are always added.
; If you are sending a UDP packet, checksum will be handled for you, too :)
; 

:SendCPacket

ff ff ff ff ff ff  ;MAC TO
00 55 00 55 00 55  ;MAC FROM (Change this)
08 00 45 00 ; IP; 20-byte header
00 2E ;Length
B3 1E ;Identification?
00 00 ;Flags & Fragment
80 ;TTL
11 ;UDP
00 00 ;CHECKSUM
C0 A8 00 67 ; Address From
FF FF FF FF 
04 00 ;Source port
34 00 ;Dest port
00 1A 2D E8 ;Length + Checksum
;Payload
43 0A AA AA AA AA AA AA AA
AA AA AA AA AA AA AA AA AA
AA AA AA AA

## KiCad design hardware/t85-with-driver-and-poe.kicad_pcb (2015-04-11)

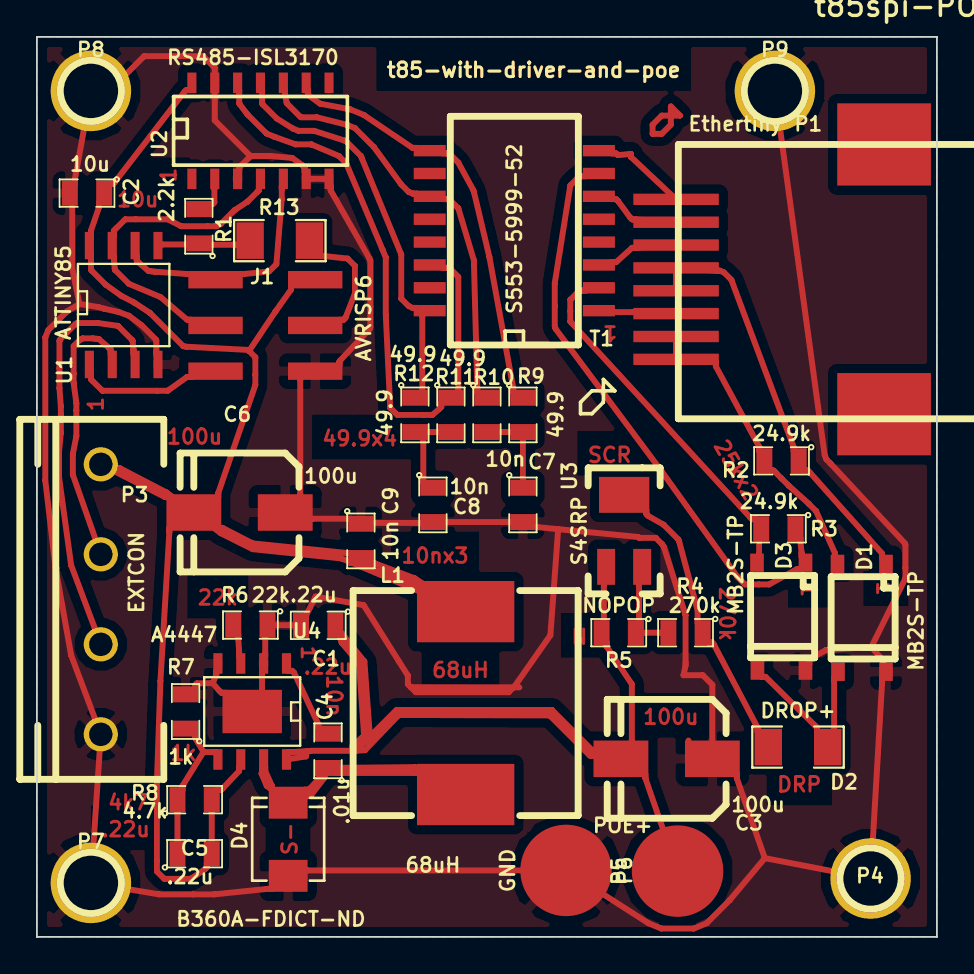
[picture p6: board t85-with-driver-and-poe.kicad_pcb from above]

Board: 2 copper layers, 50.0 x 50.0 mm, 41 parts (0 on the bottom side), 32 nets.

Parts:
C1, C5: .22u; SM0805
C2: 10u; SM0805
C3, C6: 100u; PanasonicD8Cap
C4: .01u; SM0805
C7, C8, C9: 10n; SM0805
D1, D3: MB2S-TP; BESOP-4
D2: DROP+; SM1206
D4: B360A-FDICT-ND; DO_214AA
J1: AVRISP6; RIBBON6SMT
L1: 68uH; BOURNS-SRR1280
P1: Ethertiny; SMT_ETHERNET
P3: EXTCON; PHOENIX1935187
P4, P7, P8, P9: 632HOLE
P5: POE+; .2SMTPIN
P6: GND; .2SMTPIN
R1: 2.2k; SM0805
R2, R3: 24.9k; SM0805
R4: 270k; SM0805
R5: NOPOP; SM0805
R6: 22k; SM0805
R7: 1k; SM0805
R8: 4.7k; SM0805
R9, R10, R11, R12: 49.9; SM0805
R13: 0; SM1206
T1: S553-5999-52; BELFuse-S553
U1: ATTINY85; SO8WIDE
U2: RS485-ISL3170; SO14E
U3: S4SRP; DO-214AA
U4: A4447; SO8E-WITHPAD

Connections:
unnamed: C4.2, U4.1
unnamed: C1.1, C3.1, P5.1, R5.2, U3.1, U4.8
unnamed: D1.3, D2.2, D3.3
unnamed: R4.2, R5.1, U3.2
unnamed: D2.1, R4.1, U3.3
unnamed: C8.1, R11.2, R12.2
unnamed: C7.1, R9.2, R10.2
unnamed: J1.4, R13.1
unnamed: D1.2, P1.1, P1.2, R2.2
unnamed: C5.1, R7.1, R8.1, U4.5
unnamed: R6.2, U4.3
unnamed: C4.1, D4.2, L1.1, U4.7
unnamed: P3.2, U1.2
unnamed: R10.1, T1.11, U2.10
unnamed: R9.1, T1.9, U2.9
unnamed: P1.8, T1.8
unnamed: D3.1, R3.1, T1.7
unnamed: P1.6, T1.3
unnamed: D3.2, R3.2, T1.2
unnamed: J1.5, U1.1
unnamed: P3.3, U1.3
unnamed: R12.1, T1.16, U2.11
unnamed: P1.7, T1.6
unnamed: P1.3, T1.1
unnamed: R11.1, T1.14, U2.12
unnamed: D1.1, P1.4, P1.5, R2.1
unnamed: R1.1, R13.2, U1.5
unnamed: R1.2, U2.2
unnamed: J1.1, U1.6, U2.5
unnamed: J1.3, U1.7, U2.4
VCC: C2.1, C5.2, C6.1, C9.2, J1.2, L1.2, P3.1, R8.2, U1.8, U2.14, U4.6
VSS: C1.2, C2.2, C3.2, C6.2, C7.2, C8.2, C9.1, D1.4, D3.4, D4.1, J1.6, P3.4, P4.1, P6.1, P7.1, P8.1, P9.1, R6.1, R7.2, U1.4, U2.3, U2.6, U2.7, U2.13, U4.2, U4.4, U4.9

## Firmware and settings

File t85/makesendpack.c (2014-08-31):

/*
    Copyright (C) 2014 <>< Charles Lohr


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
    THE SOFTWARE IS PROVIDED "AS IS", WITHOUT WARRANTY OF ANY KIND, EXPRESS
	OR IMPLIED, INCLUDING BUT NOT LIMITED TO THE WARRANTIES OF
	MERCHANTABILITY, FITNESS FOR A PARTICULAR PURPOSE AND NONINFRINGEMENT.
	IN NO EVENT SHALL THE AUTHORS OR COPYRIGHT HOLDERS BE LIABLE FOR ANY
	CLAIM, DAMAGES OR OTHER LIABILITY, WHETHER IN AN ACTION OF CONTRACT,
	TORT OR OTHERWISE, ARISING FROM, OUT OF OR IN CONNECTION WITH THE
	SOFTWARE OR THE USE OR OTHER DEALINGS IN THE SOFTWARE.
*/

#include <stdio.h>
#include <string.h>
#include <zlib.h>
#include <stdint.h>
#include "parsehelp.h"

int lastbit = -1;

void NewEmit()
{
	printf( "\tout PORTB, r18\n" );
	lastbit = -1;
	printf( "\teor r18, r18\n" );
	printf( "\teor r19, r19\n" );
	printf( "\teor r20, r20\n" );
	printf( "\tori r18, 0b00010101\n" );
	printf( "\tori r19, 0b00001111\n" );
	printf( "\tori r20, 0b00000101\n" );
	printf( "\tldi XH, hi8(PORTB*2)\n" );
	printf( "\tldi XL, lo8(PORTB*2)\n" );
}

void LEmit( int bit )
{
#define NAIEVE
#ifdef NAIEVE
	lastbit = -1;
	if( bit )
	{
		printf( "\tout PORTB, r18\n" );
	}
	else
	{
		printf( "\tout PORTB, r19\n" );
	}

#else
	int tlastbit = lastbit;

	if( tlastbit == bit )
	{
		if( bit )
		{
			printf( "\tst Z, r19\n" );
		}
		else
		{
			printf( "\tst Z, r18\n" );
		}
		lastbit = -1;
	}
	else
	{
		if( tlastbit != -1 )
		{
			if( bit )
			{
				printf( "\tout PORTB, r18\n" );
			}
			else
			{
				printf( "\tout PORTB, r19\n" );
			}
		}
		lastbit = bit;
	}
#endif
}

void DoneEmit()
{
	if( lastbit != -1 )
	{
		if( lastbit )
		{
			printf( "\tout PORTB, r19\n" );
		}
		else
		{
			printf( "\tout PORTB, r18\n" );
		}
	}
	printf( "\tout PORTB, r20\n\tret\n\n" );
}

void Emit( unsigned char hv )
{
	int lastbit = -1;
	printf( "\t // %02x\n", hv );

	int bit = 0x01;
	for( ; bit & 0xff; bit<<=1 )
	{
		int thisbit = (hv & bit)?1:0;
		LEmit( thisbit );
		LEmit( !thisbit );
/*
		if( thisbit )
		{
			printf( "\tout PORTB, r18\n" );
			printf( "\tout PORTB, r19\n" );
			lastbit = 1;
		}
		else
		{
			printf( "\tout PORTB, r19\n" );
			printf( "\tout PORTB, r18\n" );
			lastbit = 0;
		}
*/
	}
	printf( "\n" );
}

unsigned char sendbuf[8192];
int sbp;

uint16_t csrange( uint16_t start, uint16_t len )
{
	uint16_t i;
	uint16_t * wptr = (uint16_t*)(sendbuf + start);
	uint32_t csum = 0;
	for (i=1;i<len;i+=2)
	{
		csum = csum + (uint32_t)(*(wptr++));	
	}
	if( len & 1 )  //See if there's an odd number of bytes?
	{
		uint8_t * tt = (uint8_t*)wptr;
		csum += *tt;
	}
	while (csum>>16)
		csum = (csum & 0xFFFF)+(csum >> 16);
	csum = (csum>>8) | ((csum&0xff)<<8);
	return ~csum;
}

void EndEmit()
{
	int i;
	//Alter the headers to fix up any checksum issues.

	if( sendbuf[12] == 0x08 && sendbuf[13] == 0x00 )
	{
		fprintf( stderr, "IP Packet Doing checksum\n" );

		fprintf( stderr, "Alter length to be: %d\n", sbp-14 );
		uint16_t fullpacklen = sbp-14;
		sendbuf[16] = fullpacklen>>8;
		sendbuf[17] = fullpacklen&0xff;
		sendbuf[24] = 0;
		sendbuf[25] = 0;
		uint16_t csumr;
		fprintf( stderr, "Header checksum: 0x%04x\n", csumr = csrange(14,20) );
		sendbuf[24] = csumr>>8;
		sendbuf[25] = csumr&0xff;

		if( sendbuf[23] == 0x11  )
		{
			uint16_t udppacklen = fullpacklen-20;
			sendbuf[32+6] = udppacklen>>8;
			sendbuf[32+7] = udppacklen&0xff;
			fprintf( stderr, "UDP Packet.  Doing that checksum, too. Len: 0x%04x\n", udppacklen );
			uint16_t pseudo = 0x11 + 0x8 + udppacklen-8; //UDP number + size + length (of packet)
			sendbuf[40+0] = pseudo>>8;
			sendbuf[40+1] = pseudo&0xff;
			fprintf( stderr, "UDP checksum: 0x%04x\n", csumr = csrange(26,fullpacklen-8) );
			if( csumr == 0 ) csumr = 0xffff;
			sendbuf[40+0] = csumr>>8;
			sendbuf[40+1] = csumr&0xff;
		}
	}


	uint32_t crc = crc32( 0L, Z_NULL, 0 );
	crc = crc32( crc, sendbuf, sbp );
	fprintf( stderr, "Checksum: %08x (%d)\n", crc, sbp );

	for( i = 0; i < sbp; i++ )
	{
//		fprintf( stderr, "%02x ", sendbuf[i] );
		Emit( sendbuf[i] );
	}

	Emit( crc&0xff );
	Emit( (crc>>8)&0xff );
	Emit( (crc>>16)&0xff );
	Emit( (crc>>24)&0xff );

//TODO XXX Figure out how to send short packets.
/*
	for( i = sbp; i < 60; i++ )
	{
		Emit( 0x00 );
	}
*/

	sbp = 0;

	DoneEmit();

}

int main()
{
	char buffer[1024];
	int r;

	printf( "//Auto-generated code.\n" );
	printf( "#define _SFR_ASM_COMPAT 1\n" );
	printf( "#define __SFR_OFFSET 0\n" );
	printf( "#include <avr/io.h>\n" );
	int hassent = 0;

	while( (r = ReadBlock(stdin, ", \t\r\n", buffer, 1024)) != EOF )
	{
		if( buffer[0] == ';' )
		{
			printf( "//%s", buffer );
			while( r != EOF && r != '\n' )
			{
				printf( "%c", r );
				r = fgetc( stdin );
			}
			printf( "\n" );
			continue;
		}

		if( buffer[0] == ':' )
		{
			if( hassent )
			{
				EndEmit();
			}
			sbp = 0;
			hassent = 1;	
			printf( ".global %s\n%s:\n", &buffer[1], &buffer[1] );

			NewEmit();

			Emit( 0x55 );
			Emit( 0x55 );
			Emit( 0x55 );
			Emit( 0x55 );
			Emit( 0x55 );
			Emit( 0x55 );
			Emit( 0x55 );
			Emit( 0xD5 );


			sbp = 0;
			continue;
		}

		if( strlen( buffer ) != 2 )
		{
			fprintf	( stderr, "Error: Invalid length of element: %s\n", buffer );
		}

		//LSB First, on wire.

		const unsigned char * bf = &buffer[0];

		unsigned hv = 0;

		if( strcmp( bf, "RN" ) != 0 )
		{
			if( *bf >= '0' && *bf <= '9' ) hv |= *bf-'0';
			else if( *bf >= 'A' && *bf <= 'F' ) hv |= *bf-'A'+10;
			else if( *bf >= 'a' && *bf <= 'f' ) hv |= *bf-'a'+10;

			hv<<=4; bf++;

			if( *bf >= '0' && *bf <= '9' ) hv |= *bf-'0';
			else if( *bf >= 'A' && *bf <= 'F' ) hv |= *bf-'A'+10;
			else if( *bf >= 'a' && *bf <= 'f' ) hv |= *bf-'a'+10;
//			fprintf( stderr, " %02x(%s) ", hv, bf );
		}
		else
		{
			hv = rand()%255;
		}

		sendbuf[sbp++] = hv;
//		fprintf( stderr, "%02x\n", hv );
//		fprintf( stderr, "->%02x<-\n", hv );
	}
	EndEmit();

	return 0;
}

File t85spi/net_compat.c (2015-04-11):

#include "net_compat.h"
#include <avr/pgmspace.h>
#include <util/delay.h>
#include <string.h>
#include "hlprocess.h"
#include "packetmater.h"

#define NOOP asm volatile("nop" ::)


void SendNLP();

unsigned char ETbuffer[ETBUFFERSIZE];
unsigned short ETsendplace;
uint16_t sendbaseaddress;
unsigned short ETchecksum;


#ifdef INVERTTX
char ManchesterTable[16] __attribute__ ((aligned (16))) = {
	0b01010101, 0b10010101, 0b01100101, 0b10100101,
	0b01011001, 0b10011001, 0b01101001, 0b10101001,
	0b01010110, 0b10010110, 0b01100110, 0b10100110,
	0b01011010, 0b10011010, 0b01101010, 0b10101010,
};
#else
//Do not split this across byte-addressing boundaries.
//We do some fancy stuff when we send the manchester out.
char ManchesterTable[16] __attribute__ ((aligned (16))) = {
	0b10101010, 0b01101010, 0b10011010, 0b01011010,
	0b10100110, 0b01100110, 0b10010110, 0b01010110,
	0b10101001, 0b01101001, 0b10011001, 0b01011001,
	0b10100101, 0b01100101, 0b10010101, 0b01010101,
};
#endif


//Internal functs

uint32_t crc32b(uint32_t crc, unsigned char *message, int len) {
   int i, j;
   uint32_t mask;
	uint8_t byte;

   i = 0;
//   crc = 0xFFFFFFFF;
	crc = ~crc;
   while (i < len) {
      byte = message[i];            // Get next byte.
      crc = crc ^ byte;
      for (j = 7; j >= 0; j--) {    // Do eight times.
         mask = -(crc & 1);
         crc = (crc >> 1) ^ (0xEDB88320 & mask);
      }
      i = i + 1;
   }
   return ~crc;
}

uint16_t internet_checksum( const unsigned char * start, uint16_t len )
{
	uint16_t i;
	const uint16_t * wptr = (uint16_t*) start;
	uint32_t csum = 0;
	for (i=1;i<len;i+=2)
	{
		csum = csum + (uint32_t)(*(wptr++));	
	}
	if( len & 1 )  //See if there's an odd number of bytes?
	{
		uint8_t * tt = (uint8_t*)wptr;
		csum += *tt;
	}
	while (csum>>16)
		csum = (csum & 0xFFFF)+(csum >> 16);
	csum = (csum>>8) | ((csum&0xff)<<8);
	return ~csum;
}



//From the ASM file.
void SendTestASM( const unsigned char * c, uint8_t len );
int MaybeHaveDataASM( unsigned char * c, uint8_t lenX2 ); //returns the number of pairs.

//Must be at 
uint8_t MaybeHaveAPacket()
{
	//if( 0 )
	{
		uint8_t usir;
		//Wait 8 cycles, to see what the incoming data looks like.
		NOOP; NOOP; NOOP; NOOP; NOOP; NOOP; NOOP; NOOP; NOOP;
		if( USIDR == 0 || USIDR == 0xFF )
		{
			return 0;
		}
	}

	int r = MaybeHaveDataASM( ETbuffer, (ETBUFFERSIZE/2)-4 );
	if( r > 10 )
	{
		ETbuffer[ETBUFFERSIZE-1] = 0; //Force an end-of-packet.
		int16_t byr = Demanchestrate( ETbuffer, ETBUFFERSIZE-1 );
		if( byr > 32 )
		{
			uint32_t cmpcrc = crc32b( 0, ETbuffer, byr - 4 );
			OSCCAL = OSC20; //Drop back to 20 MHz if we need to send.
			if( cmpcrc == *((uint32_t*)&ETbuffer[byr-4]) )
			{
				//LRP( "%d->%d\n", r, byr );

				//If you ever get to this code, a miracle has happened.
				//Pray that many more continue.
				ETsendplace = 0;
				et_receivecallback( byr - 4 );
			}
		}
		OSCCAL = OSCHIGH;
		return byr/4+1;
	}

	return 0;
//	ltime-=(len-r)*4+3; //About how long the function takes to execute.
}

/*
void waitforpacket( unsigned char * buffer, uint16_t len, int16_t ltime )
{
//	OSCCAL = OSCHIGH;

	while( ltime-- > 0 )
	{
		MaybeHaveAPacket();
	}
	OSCCAL = OSC20;

	while( ltime-- > 0 )
	{
		NOOP;
		NOOP;
		NOOP;
		NOOP;
		NOOP;
	}

	OSCCAL = OSC20;
}
*/








//
uint16_t et_pop16()
{
	uint16_t ret = et_pop8();
	return (ret<<8) | et_pop8();
}

void et_popblob( uint8_t * data, uint8_t len )
{
	while( len-- )
	{
		*(data++) = et_pop8();
	}
}

void et_pushpgmstr( const char * msg )
{
	uint8_t r;
	do
	{
		r = pgm_read_byte(msg++);
		if( !r ) break;
		et_push8( r );
	} while( 1 );
}

void et_pushpgmblob( const uint8_t * data, uint8_t len )
{
	while( len-- )
	{
		et_push8( pgm_read_byte(data++) );
	}
}


void et_pushstr( const char * msg )
{
	for( ; *msg; msg++ ) 
		et_push8( *msg );
}

void et_pushblob( const uint8_t * data, uint8_t len )
{
	while( len-- )
	{
		et_push8( *(data++) );
	}
}

void et_push16( uint16_t p )
{
	et_push8( p>>8 );
	et_push8( p&0xff );
}


//return 0 if OK, otherwise nonzero.
int8_t et_init( const unsigned char * macaddy )
{
	MyMAC[0] = macaddy[0];
	MyMAC[1] = macaddy[1];
	MyMAC[2] = macaddy[2];
	MyMAC[3] = macaddy[3];
	MyMAC[4] = macaddy[4];
	MyMAC[5] = macaddy[5];

	PLLCSR = _BV(PLLE) | _BV( PCKE );
	OSCCAL = OSC20;


	//Setup timer 0 to speed along.
	//It will become useless for any other uses.
	TCCR0A = _BV(WGM01); //CTC mode.
	TCCR0B = _BV(CS00);  //Use system clock with no divisor.
	OCR0A = 0;

	USICR = _BV(USIWM0) | _BV(USICS0) | _BV(USITC);

#ifdef USES_EXTERNAL_DRIVER
	DDRB &= ~_BV(0);
	DDRB |= _BV(1);
	DDRB |= _BV(2);
	USICR &= ~_BV(USIWM0);  //Disable USICR


#else //Doesn't use external driver

	//setup port B
	PORTB &= ~_BV(0); 
	DDRB &= ~_BV(0);
	PORTB &= ~_BV(1);
	USICR &= ~_BV(USIWM0);  //Disable USICR

#ifdef SMARTDDR
	DDRB &= _BV(1);
#else
	DDRB |= _BV(1);
#endif


	//Optional, changes bias.
	//2k -> GND/2k ->5V seems best with this on
	//Doesn't change much with it off. 2k/2k it is.
#ifdef BIAS0
	PORTB &= ~_BV(0);
#else
	PORTB |= _BV(0);
#endif

#endif

	return 0;
}

int8_t et_xmitpacket( uint16_t start, uint16_t len )
{
	//If we're here, ETbuffer[start] points to the first byte (dst MAC address)
	//Gotta calculate the checksum.

	//First, round up the length and make sure it meets minimum requirements.
	if( len < 60 ) len = 60;
	len = ((len-1) & 0xfffc) + 4; //round up to 4.

	uint8_t  * buffer = &ETbuffer[start];
	uint32_t crc = crc32b( 0, buffer, len );
	uint16_t i = start + len;
	
	buffer[i++] = crc & 0xff;
	buffer[i++] = (crc>>8) & 0xff;
	buffer[i++] = (crc>>16) & 0xff;
	buffer[i++] = (crc>>24) & 0xff;

	//Actually emit the packet.
	SendTestASM( buffer, (len>>2) + 1 ); //Don't forget the CRC!

	return 0;
}

/*
//This waits for 8ms, sends an autoneg notice, then waits for 8 more ms.
unsigned short et_recvpack()
{
	//Right up to the wire limit. 
	//If ETBUFFERSIZE = 352, Our clock is at 31.5 MHz and this limit, we can send ping packets with
	//92 bytes on-wire.  Keep in mind the preamble takes a little chunk.
	//92 bytes on-wire means we can ping packets up to -s 50
	#define LIMITSIZE  sizeof( ETbuffer )/2-4

		waitforpacket(&ETbuffer[0], LIMITSIZE, 11000); //~8ms


		SendNLP();
		waitforpacket(&ETbuffer[0], LIMITSIZE, 11000); //~8ms
// 		_delay_ms(8);

	return 0;
}
*/
unsigned short et_recvpack()
{
	//Stub function.
	return 0;
}

void et_start_checksum( uint16_t start, uint16_t len )
{
	uint16_t i;
	const uint16_t * wptr = (uint16_t*)&ETbuffer[start];
	uint32_t csum = 0;
	for (i=1;i<len;i+=2)
	{
		csum = csum + (uint32_t)(*(wptr++));	
	}
	if( len & 1 )  //See if there's an odd number of bytes?
	{
		uint8_t * tt = (uint8_t*)wptr;
		csum += *tt;
	}
	while (csum>>16)
		csum = (csum & 0xFFFF)+(csum >> 16);
	csum = (csum>>8) | ((csum&0xff)<<8);
	ETchecksum = ~csum;
}
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

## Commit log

2014-08-29 tweak - add option for nop's... it doesn't help.
    [makesendpack.c]
2014-08-30 first shot at SPI-style xmit.
2014-08-30 further progress toward a bi-directional ethernet device. Not sure if t's gonna be possible at all, but it's a fun try.
2014-08-30 Fixed a number of bugs, now accept packets on-wire and write their contens to the buffer and re-broadcast.
    [test.c]
2014-08-31 Another checkin. Get rid of the user having to handle the preamble noise
    [net_compat.c, test.c]
2014-09-01 hoorey! tweaks! Now we have ADC + WS2812
2014-09-01 add topside control, plus fix port #'s.
    [test.c]
2014-09-02 Add "hict" and "loct" for debugging the bias system on the AVR. This also helps diagnose when soemthing's wrong and packets are coming in stunted.
    [net_compat.c, test.c]
2014-09-04 down to a lower pcket loss + linking with switches a good clip away.
2014-09-04 Add in some schematics
    [t85-with-driver.kicad_pcb, t85.sch, t85spi-with-driver.sch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]
2014-09-04 add schematic
2014-09-05 pretty big changes, make everything interrupt driven.
2014-09-05 fix orientation of pins
    [t85spi.sch]
2014-09-05 add documentation + warnings
    [t85-with-driver.kicad_pcb, t85.sch, t85spi.sch]
2015-04-11 update with the poe
    [t85-with-driver-and-poe-B_Cu.gbl, t85-with-driver-and-poe-B_Mask.gbs, t85-with-driver-and-poe-B_SilkS.gbo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]
2015-04-11 add a driver version... it doesn't seem to work off the bat, but we can work with it.
    [net_compat.c]

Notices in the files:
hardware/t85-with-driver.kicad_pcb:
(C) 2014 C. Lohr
